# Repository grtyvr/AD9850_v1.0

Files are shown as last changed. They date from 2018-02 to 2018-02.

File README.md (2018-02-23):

# AD9850_v1.0
Larger version of the board for the SigGen project: 328p based AD9850 function generator.

It is based on the project:

http://www.vwlowen.co.uk/arduino/AD9850-waveform-generator/AD9850-waveform-generator.htm

Which in turn is based on AD9851 code from Andrew Smallbone - modified for AD9850
   http://www.rocketnumbernine.com/2011/10/25/programming-the-ad9851-dds-synthesizer

I have created the KiCad files for a board for this project.  This version takes out the 100K current limiting resistor for the display led (on is on the board already).  And it is powered not by a power jack but by pin header from a seperate power supply in the same case.

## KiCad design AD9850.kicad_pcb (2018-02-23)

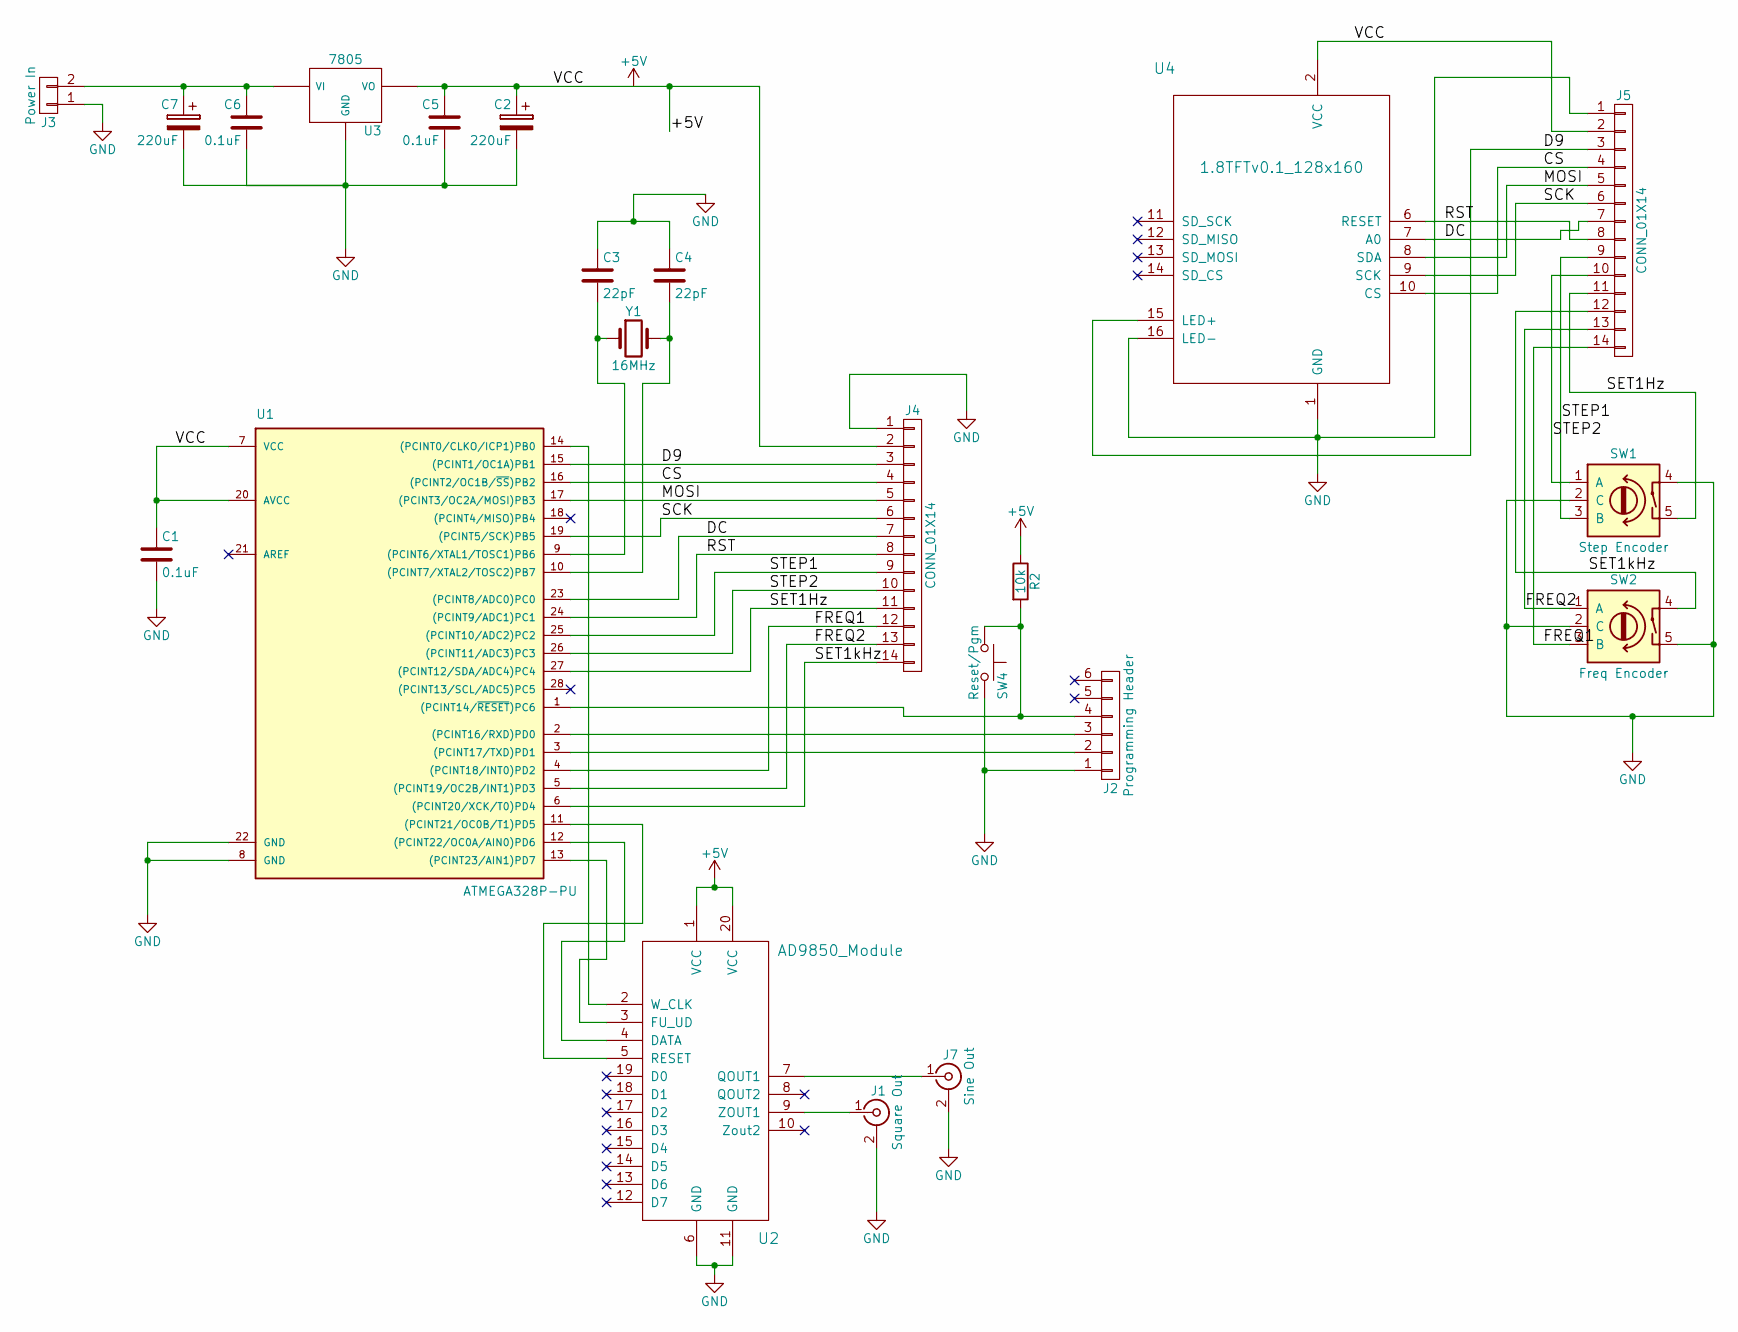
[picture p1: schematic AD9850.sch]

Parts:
C1, C5: 0.1uF; C_Disc_D3.0mm_W1.6mm_P2.50mm
C2, C7: 220uF; CP_Radial_D8.0mm_P3.50mm
C3, C4: 22pF; C_Disc_D3.0mm_W1.6mm_P2.50mm
C6: 0.1uF; C_Disc_D3.0mm_W2.0mm_P2.50mm
J1: Square Out; BNC_Socket_TYCO-AMP
J2: Programming Header; Pin_Header_Straight_1x06_Pitch2.54mm
J3: Power In; GTK2400-V2
J4, J5: CONN_01X14; Pin_Header_Straight_1x14_Pitch2.54mm
J7: Sine Out; BNC_Socket_TYCO-AMP
R2: 10k; D3
SW1: Step Encoder; SF-ROTARY-ENCODER
SW2: Freq Encoder; SF-ROTARY-ENCODER
SW4: Reset/Pgm; SW_PUSH_6mm
U1: ATMEGA328P-PU; DIP-28_W7.62mm
U2: AD9850_Module; DS9850_Module
U3: 7805; TO-220
U4: 1.8TFTv0.1_128x160; 128x160-SPI_w_SD-CARD
Y1: 16MHz; Crystal_AT310_d3.0mm_l10.0mm_Horizontal

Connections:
+5V: C1.1, C2.1, C5.1, J4.2, J5.2, R2.1, U1.7 (VCC), U1.20 (AVCC), U2.1 (VCC), U2.20 (VCC), U3.VO, U4.2 (VCC)
/CS: J4.4, J5.4, U1.16 ((PCINT2/OC1B/~SS~)PB2), U4.10 (CS)
/D9: J4.3, J5.3, U1.15 ((PCINT1/OC1A)PB1), U4.15 (LED+)
/DC: J4.7, J5.7, U1.23 ((PCINT8/ADC0)PC0), U4.7 (A0)
/FREQ1: J4.12, J5.14, SW2.3 (B), U1.4 ((PCINT18/INT0)PD2)
/FREQ2: J4.13, J5.13, SW2.1 (A), U1.5 ((PCINT19/OC2B/INT1)PD3)
/MOSI: J4.5, J5.5, U1.17 ((PCINT3/OC2A/MOSI)PB3), U4.8 (SDA)
/RST: J4.8, J5.8, U1.24 ((PCINT9/ADC1)PC1), U4.6 (RESET)
/SCK: J4.6, J5.6, U1.19 ((PCINT5/SCK)PB5), U4.9 (SCK)
/SET1Hz: J4.11, J5.11, SW1.5, U1.27 ((PCINT12/SDA/ADC4)PC4)
/SET1kHz: J4.14, J5.12, SW2.4, U1.6 ((PCINT20/XCK/T0)PD4)
/STEP1: J4.9, J5.9, SW1.3 (B), U1.25 ((PCINT10/ADC2)PC2)
/STEP2: J4.10, J5.10, SW1.1 (A), U1.26 ((PCINT11/ADC3)PC3)
GND: C1.2, C2.2, C3.1, C4.1, C5.2, C6.2, C7.2, J1.2 (Ext), J2.1, J3.1, J4.1, J5.1, J7.2 (Ext), SW1.2 (C), SW1.4, SW2.2 (C), SW2.5, SW4.2, U1.8 (GND), U1.22 (GND), U2.6 (GND), U2.11 (GND), U3.GND, U4.1 (GND), U4.16 (LED-)
unnamed: C3.2, U1.9 ((PCINT6/XTAL1/TOSC1)PB6), Y1.1
unnamed: C4.2, U1.10 ((PCINT7/XTAL2/TOSC2)PB7), Y1.2
unnamed: C6.1, C7.1, J3.2, U3.VI
unnamed: J1.1 (In), U2.9 (ZOUT1)
unnamed: J2.2, U1.3 ((PCINT17/TXD)PD1)
unnamed: J2.3, U1.2 ((PCINT16/RXD)PD0)
unnamed: J2.4, R2.2, SW4.1, U1.1 ((PCINT14/~RESET~)PC6)
unnamed: J7.1 (In), U2.7 (QOUT1)
unnamed: U1.11 ((PCINT21/OC0B/T1)PD5), U2.5 (RESET)
unnamed: U1.12 ((PCINT22/OC0A/AIN0)PD6), U2.4 (DATA)
unnamed: U1.13 ((PCINT23/AIN1)PD7), U2.3 (FU_UD)
unnamed: U1.14 ((PCINT0/CLKO/ICP1)PB0), U2.2 (W_CLK)

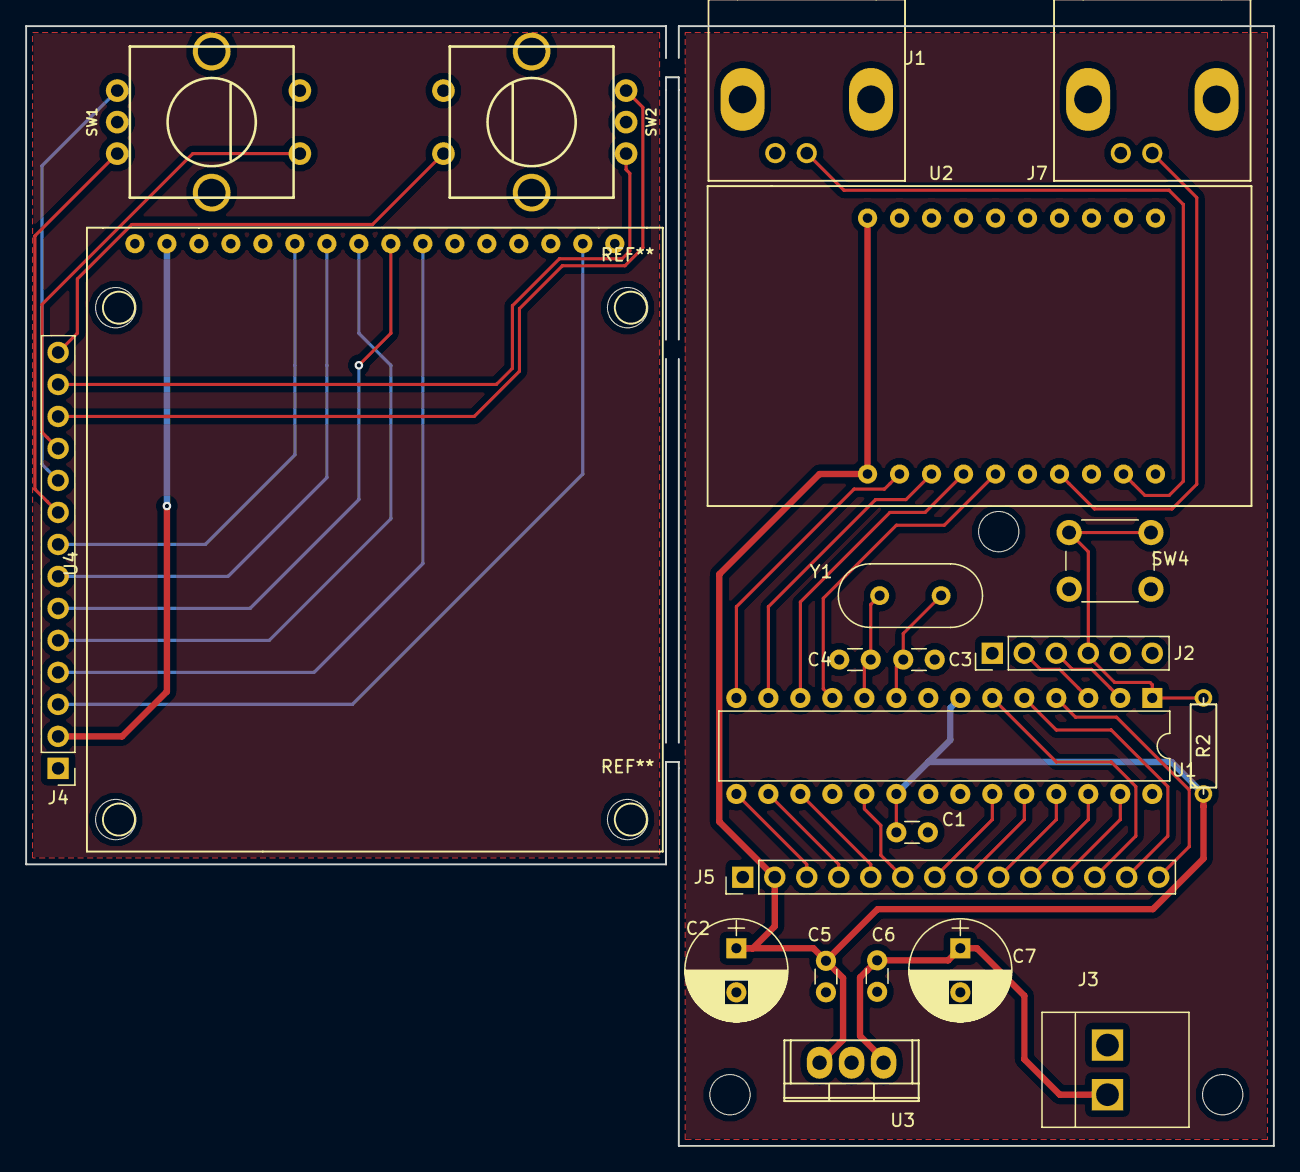
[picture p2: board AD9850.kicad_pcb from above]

Board: 2 copper layers, 99.1 x 88.9 mm, 22 parts (0 on the bottom side), 26 nets.

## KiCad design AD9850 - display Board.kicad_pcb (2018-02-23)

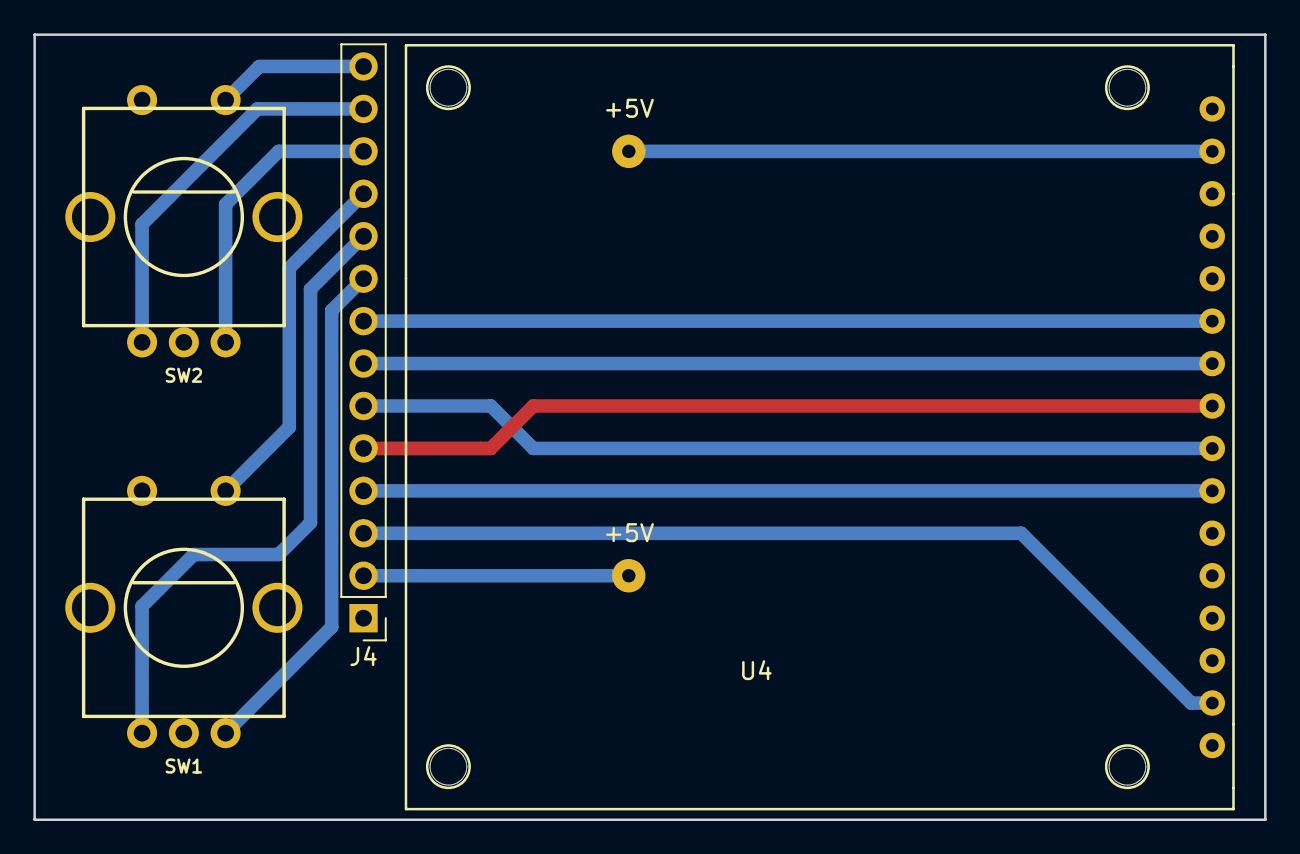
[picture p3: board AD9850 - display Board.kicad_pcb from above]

Board: 2 copper layers, 73.7 x 47.0 mm, 6 parts (0 on the bottom side), 14 nets.

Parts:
+5V, +5V#2: JP2; SolderWirePad_single_0-8mmDrill
J4: CONN_01X14; Pin_Header_Straight_1x14_Pitch2.54mm
SW1, SW2: Rotary_Encoder_Switch; SF-ROTARY-ENCODER
U4: 1.8TFTv0.1_128x160; 128x160-SPI_w_SD-CARD

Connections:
+5V: +5V.1, +5V#2.1, J4.2, U4.2
/CS: J4.4, U4.10
/D9: J4.3, U4.15
/DC: J4.7, U4.7
/FREQ1: J4.12, SW2.3
/FREQ2: J4.13, SW2.1
/MOSI: J4.5, U4.8
/RST: J4.8, U4.6
/SCK: J4.6, U4.9
/SET1Hz: J4.11, SW1.5
/SET1kHz: J4.14, SW2.5
/STEP1: J4.9, SW1.3
/STEP2: J4.10, SW1.1
GND: J4.1, SW1.2, SW1.4, SW2.2, SW2.4, U4.1, U4.16

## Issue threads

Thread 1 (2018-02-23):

SPI display footprint is wrong

grtyvr, 2018-02-23:
128x160-SPI footprint has mounting holes in the wrong place.
